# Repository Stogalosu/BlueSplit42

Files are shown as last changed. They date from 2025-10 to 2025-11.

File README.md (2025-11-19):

# Bluesplit42
## What?(description)
Bluesplit42 is a split custom mechanical keyboard built entirely by me, except for the switches and keycaps. It will be a 40% layout with 42 keys, thus the 42 in the name.
It will have linear switches and pom jelly keycaps, because I've always wanted those but they were too expensive (now they're on sale). For the firmware, I'm using ZMK

## But Why?
Simply because i love mechanical keyboards. I just love them. Plus, this event is a great way to get a keyboard that would otherwise be very expensive for my budget. Did I mention I love keyboards?

**3D Render**



**Left PCB**



**Right PCB**



**Full PCB with mousebites**



**Wiring diagram for the left PCB**



**Wiring diagram for the right PCB**



**Bom table**
|Name |Unit Price|Shipping|Amount|Total Cost|Notes |Link |
|---|---|---|---|---|---|---|
|Case |$0.00 |$0.00 |1 |$0.00 |3D Printed in-house |No link |
|Keycaps |$0.00 |$0.00 |1 |$0.00 |3D Printed in-house |No link |
|Gateron Milky Yellow Switches|$15.46 |$0.00 |1 |$15.46 |50pcs |https://www.aliexpress.com/item/1005006425450443.html|
|Hotswap Sockets |$4.79 |$0.00 |1 |$4.79 |70pcs/Color: Type 1 |https://www.aliexpress.com/item/1005008954571807.html|
|Durock Stabiliers |$2.45 |$7.87 |2 |$12.77 |Color: V3-2u Teal |https://www.aliexpress.com/item/1005002192386317.html|
|XIAO NRF52840 Microcontroller|$18.63 |$6.11 |2 |$43.37 | |https://www.tme.eu/ro/details/seeed-102010448 |
|1N4148W-7-F Diodes |$0.08 |$0.00 |50 |$4.14 |They come with the microcontrollers|https://www.tme.eu/ro/en/details/1n4148w-e3-08/smd-universal-diodes/vishay|
|AKY0386 Batteries |$5.32 |$0.00 |2 |$10.64 |They come with the microcontrollers|https://www.tme.eu/ro/details/aky-lp403035 |
|PCB |$20.16 |$7.55 |1 |$27.71 |From JLCPCB |No link |
|Total Cost | | | |$118.88 | | |

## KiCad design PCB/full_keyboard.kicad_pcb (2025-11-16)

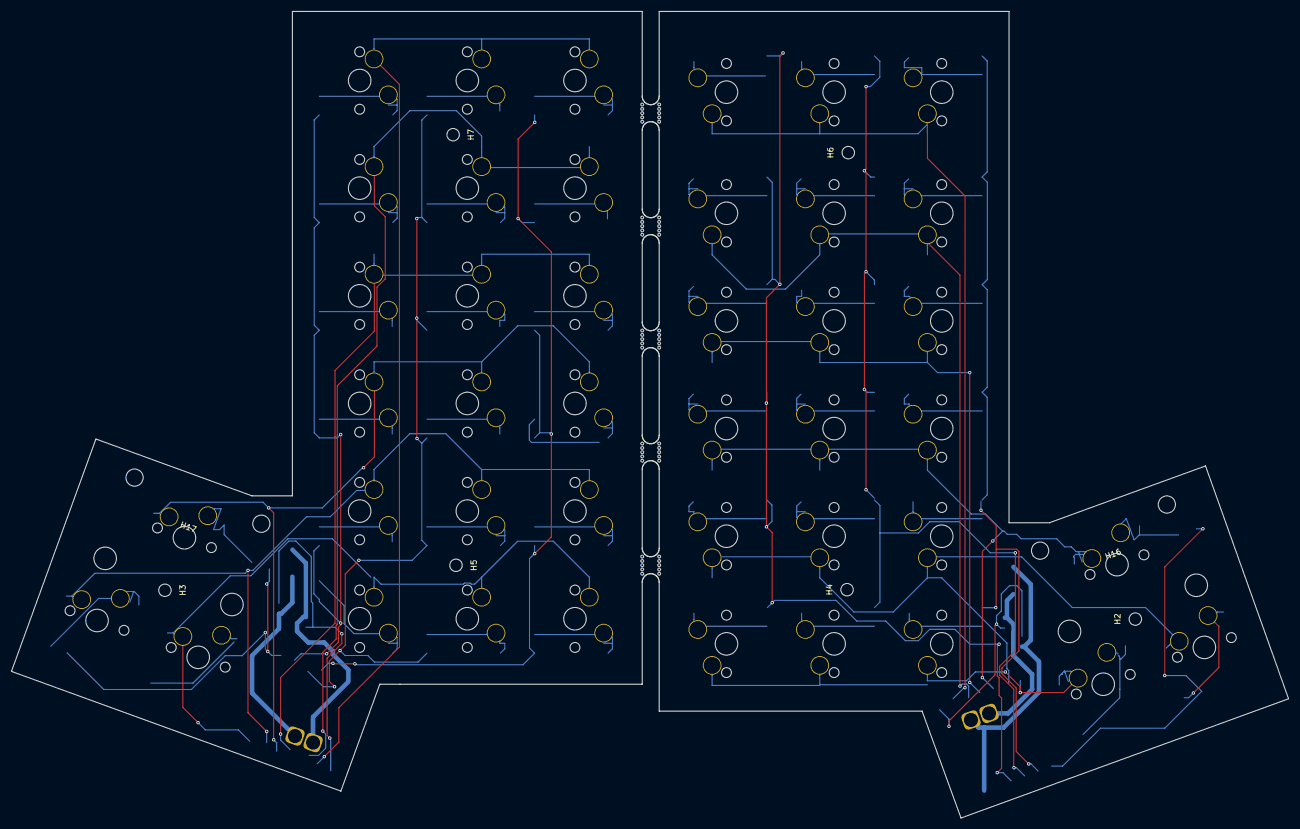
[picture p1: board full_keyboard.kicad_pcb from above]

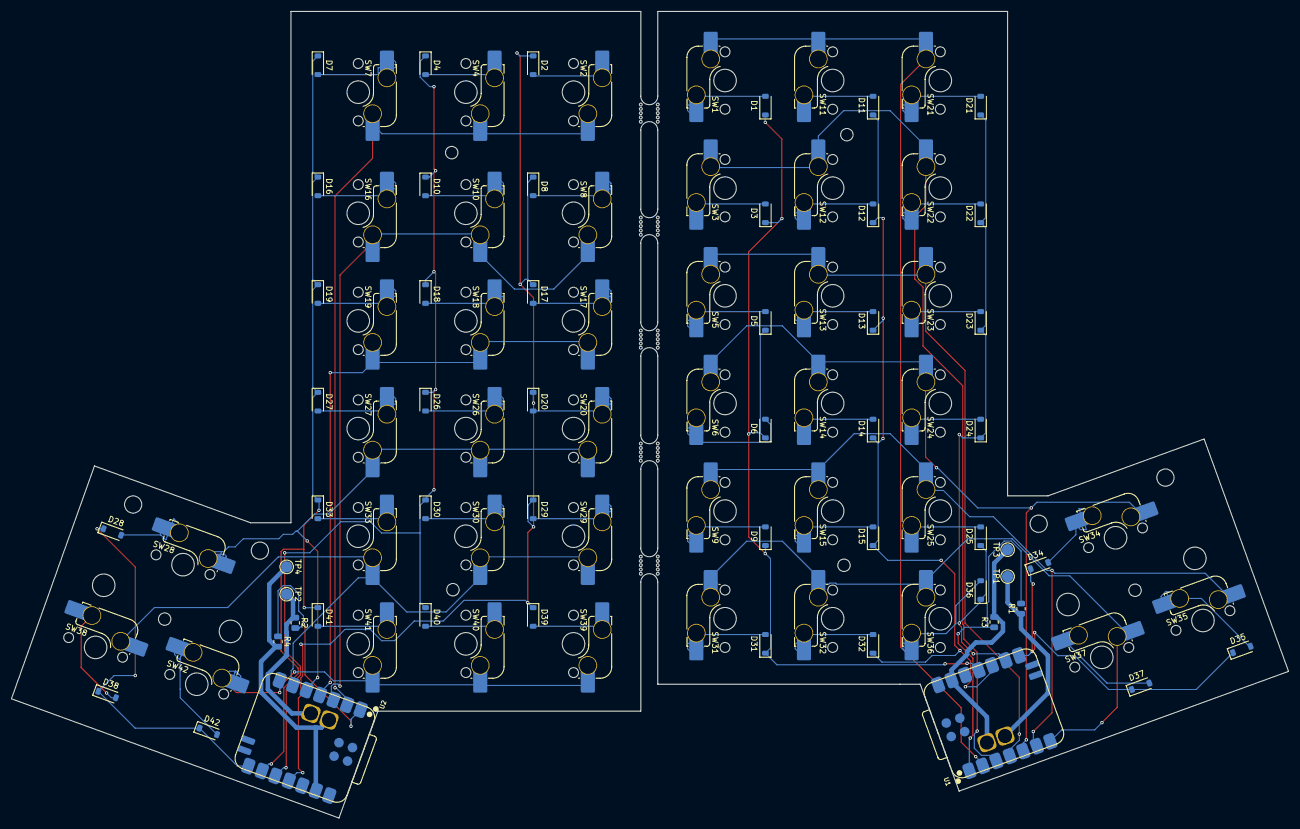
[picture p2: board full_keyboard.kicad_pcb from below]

Board: 2 copper layers, 226.0 x 142.7 mm, 107 parts (94 on the bottom side), 67 nets.

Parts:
D1, D2, D3, D4, D5, D6, D7, D8, D9, D10, D11, D12, D13, D14, D15, D16, D17, D18, D19, D20, D21, D22, D23, D24, D25, D26, D27, D28, D29, D30, D31, D32, D33, D34, D35, D36, D37, D38, D39, D40, D41, D42: D; D_SOD-123
H2, H3, H4, H5, H6, H7: MountingHole; MountingHole_2.2mm_M2
H13, H19, H20, H21, H22: MountingHole; mouse-bite-3mm-slot
H16, H17: MountingHole; Stabilizer_Cherry_MX_2.00u
R1, R2: 806K; R_0805_2012Metric
R3, R4: 2M; R_0805_2012Metric
SW1, SW3, SW5, SW6, SW8, SW9, SW10, SW11, SW12, SW13, SW14, SW15, SW16, SW17, SW18, SW19, SW20, SW21, SW22, SW23, SW24, SW25, SW26, SW27, SW28, SW29, SW30, SW31, SW32, SW33, SW34, SW35, SW36, SW37, SW38, SW39, SW40, SW41, SW42: SW_Push; SW_MX_HS_CPG151101S11_1u
SW2, SW4, SW7: SW_Push; SW_MX_HS_CPG151101S11_1.25u
TP1, TP2: BAT; TestPoint_Pad_D2.0mm
TP3, TP4: GND; TestPoint_Pad_D2.0mm
U1, U2: XIAO-nRF52840-SMD; modified-XIAO-nRF52840-SMD

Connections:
/left/BT_PIN: R1.2, R3.1, U1.1 (P0.02_A0_D0)
/left/COL0: SW1.1, SW11.1, SW21.1, U1.2 (P0.03_A1_D1)
/left/COL1: SW3.1, SW12.1, SW22.1, U1.3 (P0.28_A2_D2)
/left/COL2: SW5.1, SW13.1, SW23.1, U1.4 (P0.29_A3_D3)
/left/COL3: SW6.1, SW14.1, SW24.1, SW34.1, U1.5 (P0.04_A4_D4_SDA)
/left/COL4: SW9.1, SW15.1, SW25.1, SW35.1, U1.6 (P0.05_A5_D5_SCL)
/left/COL5: SW31.1, SW32.1, SW36.1, SW37.1, U1.7 (P1.11_D6_TX)
/left/ROW0: D1.1 (K), D3.1 (K), D5.1 (K), D6.1 (K), D9.1 (K), D31.1 (K), U1.11 (P1.15_D10_MOSI)
/left/ROW1: D11.1 (K), D12.1 (K), D13.1 (K), D14.1 (K), D15.1 (K), D32.1 (K), U1.10 (P1.14_D9_MISO)
/left/ROW2: D21.1 (K), D22.1 (K), D23.1 (K), D24.1 (K), D25.1 (K), D36.1 (K), U1.9 (P1.13_D8_SCK)
/left/ROW3: D34.1 (K), D35.1 (K), D37.1 (K), U1.8 (P1.12_D7_RX)
/left/VBAT: R1.1, TP1.1, U1.15 (BAT)
/right/BT_PIN: R2.2, R4.1, U2.1 (P0.02_A0_D0)
/right/COL0: SW2.1, SW4.1, SW7.1, U2.2 (P0.03_A1_D1)
/right/COL1: SW8.1, SW10.1, SW16.1, U2.3 (P0.28_A2_D2)
/right/COL2: SW17.1, SW18.1, SW19.1, U2.4 (P0.29_A3_D3)
/right/COL3: SW20.1, SW26.1, SW27.1, SW28.1, U2.5 (P0.04_A4_D4_SDA)
/right/COL4: SW29.1, SW30.1, SW33.1, SW38.1, U2.6 (P0.05_A5_D5_SCL)
/right/COL5: SW39.1, SW40.1, SW41.1, SW42.1, U2.7 (P1.11_D6_TX)
/right/ROW0: D2.1 (K), D8.1 (K), D17.1 (K), D20.1 (K), D29.1 (K), D39.1 (K), U2.11 (P1.15_D10_MOSI)
/right/ROW1: D4.1 (K), D10.1 (K), D18.1 (K), D26.1 (K), D30.1 (K), D40.1 (K), U2.10 (P1.14_D9_MISO)
/right/ROW2: D7.1 (K), D16.1 (K), D19.1 (K), D27.1 (K), D33.1 (K), D41.1 (K), U2.9 (P1.13_D8_SCK)
/right/ROW3: D28.1 (K), D38.1 (K), D42.1 (K), U2.8 (P1.12_D7_RX)
/right/VBAT: R2.1, TP2.1, U2.15 (BAT)
GND: R3.2, R4.2, TP3.1, TP4.1, U1.13 (GND), U1.16 (GND), U2.13 (GND), U2.16 (GND)
unnamed: D1.2 (A), SW1.2
unnamed: D2.2 (A), SW2.2
unnamed: D3.2 (A), SW3.2
unnamed: D4.2 (A), SW4.2
unnamed: D5.2 (A), SW5.2
unnamed: D6.2 (A), SW6.2
unnamed: D7.2 (A), SW7.2
unnamed: D8.2 (A), SW8.2
unnamed: D9.2 (A), SW9.2
unnamed: D10.2 (A), SW10.2
unnamed: D11.2 (A), SW11.2
unnamed: D12.2 (A), SW12.2
unnamed: D13.2 (A), SW13.2
unnamed: D14.2 (A), SW14.2
unnamed: D15.2 (A), SW15.2
unnamed: D16.2 (A), SW16.2
unnamed: D17.2 (A), SW17.2
unnamed: D18.2 (A), SW18.2
unnamed: D19.2 (A), SW19.2
unnamed: D20.2 (A), SW20.2
unnamed: D21.2 (A), SW21.2
unnamed: D22.2 (A), SW22.2
unnamed: D23.2 (A), SW23.2
unnamed: D24.2 (A), SW24.2
unnamed: D25.2 (A), SW25.2
unnamed: D26.2 (A), SW26.2
unnamed: D27.2 (A), SW27.2
unnamed: D28.2 (A), SW28.2
unnamed: D29.2 (A), SW29.2
unnamed: D30.2 (A), SW30.2
unnamed: D31.2 (A), SW31.2
unnamed: D32.2 (A), SW32.2
unnamed: D33.2 (A), SW33.2
unnamed: D34.2 (A), SW34.2
unnamed: D35.2 (A), SW35.2
unnamed: D36.2 (A), SW36.2
unnamed: D37.2 (A), SW37.2
unnamed: D38.2 (A), SW38.2
unnamed: D39.2 (A), SW39.2
unnamed: D40.2 (A), SW40.2
unnamed: D41.2 (A), SW41.2
unnamed: D42.2 (A), SW42.2

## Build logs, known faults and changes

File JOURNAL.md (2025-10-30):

<!--
  ===================    !!READ THIS NOTICE!!   ====================
  DO NOT edit this file manually. Your changes WILL BE OVERWRITTEN!
  This journal is auto generated and updated by Hack Club Blueprint.
  To edit this file, please edit your journal entries on Blueprint.
  ==================================================================
-->

## 10/16/2025 - Created the schematic  

I started by installing KiCad and creating the schematic for the PCB. By following the guide, I added buttons according to my own layout, along with diodes for each one and a microcontroller. I had some trouble with the pieces library, but I figured it out.



## 10/17/2025 - Started work on the PCB layout  

I started the PCB layout by arranging the switch footprints in KiCad, simply following the schematic I made yesterday.
However, the process was not completely smooth, at first I did the right side wrong and had to redo it, then when I wanted to arrange the thumb keys i had trouble rotating them.



## 10/19/2025 - Finished the PCB  

Today, I arranged the diodes for each switch, then I routed the whole PCB. I also placed some footprints for the pins that connect to the battery and the mounting holes.
This time, i had trouble because initially I routed the pinholes to the microcontroller instead of the hotswap sockets, so I had to redo most of the wiring. Also, rotating the thumb keys almost gave me a headache again.



## 10/25/2025 - Started designing the case  

I started designing the case for the keyboard in Fusion 360. Fortunately, I already know how to use Fusion, so it isn't that hard. I still have to figure out how to hold the whole thing together.



## 10/26/2025 - Redid the PCB  

I realized that the switch sockets were on the wrong side, so I had to redesign the PCB. This time, I used a autorouting plugin to make the wiring quicker. I also made a panelized version, to check if it's cheaper this way (it isn't). While I was at it, I also fixed some outlines that weren't at the right angles.



## 10/30/2025 - Finished the case  

After redesigning the PCB, I completely redesigned the case as well. It has two parts: the bottom one, which holds the battery and has the opening for the USB C port and the top one, that also acts as a mount plate for the switches. Everything is held together by 3 M3 screws. I initially used M2 screws, but I realized the threads were kind of small to be 3d printed. I also added an incline to the case for comfort.




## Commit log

2025-11-10 Enhance README formatting and add PCB images
    Updated README.md to improve formatting and add images.
2025-11-14 Insert 3D render image in README
    Added a 3D render image to the README.
2025-11-15 Added BOM.csv file
    [BOM.csv]
2025-11-15 Create PCB
2025-11-16 Revise README structure and add BOM table
2025-11-16 Added project files
    [BOM.csv, full_keyboard.kicad_pcb, full_keyboard.kicad_sch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]
2025-11-16 Rename full_keyboard.kicad_pro file
2025-11-16 Modified diodes link in CSV
    [BOM.csv]
2025-11-18 Update PCB cost and total cost in README
2025-11-18 Update note on full PCB cost in README
    Clarified note about the full PCB with mousebites being more expensive than purchasing two separate PCBs.
2025-11-18 Clarify note about full PCB pricing
2025-11-19 Update PCB details and total cost in README
2025-11-19 Revise component prices and total cost in BOM.csv
    Updated prices and shipping costs for components in BOM.
    [BOM.csv]
2025-11-27 Updated gerber files to include drill files
